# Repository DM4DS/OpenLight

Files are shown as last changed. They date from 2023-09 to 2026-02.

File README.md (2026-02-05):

# OpenLight
OpenLight is an OpenSource alternative to the copyrighted UniLight.
So feel free to mod / share / whatever you like.

#update 05.02.2026

Uploaded a schematic - not proud of it but better than nothing.
Pay attention, if you use a different Arduino, that your PINs must maybe adapted.
I am almost sure that not all Arduinos Pin 9 is a PWM pin. Maybe it is, check that!
Also with the Output bin. If you Arduino has more then 1 Output Pin with the same number, just try the other one.
Nothing should happen if you connect it to the wrong one. Test it wih a normal LED before you flashbang a 200W LED...

Hope you enjoy the project as I do and feel free to use it for whatever you wanna control on your RC Car / Plane / Boat / submarine / UFO .....

#update 17.05.2024:

Uploaded a new INO especially for WS2812 LED strips/Plates with super easy to configure large number LED strips/plates.
You no longer have to write EACH Led per line!
NO, now tell your max number and ALL LEDs are lighting /turn off with 1 single line of code!
Also included a random pattern, with random coloring as example!
Try it, it is in the file:
OpenLight_DM4DS_v1_64er_RND_-Channel_PMW_WS2812_flash_v2.ino

#update 20.nov.2013:
Now OpenLight supports WS2812 programmable LEDs!
Thanks to AdaFruit for the library.
_________________________________________
If you have questions, please first look into the code. Most lines are commented.
If you still have questions, feal free to ask!

What to do:
- Update the parts list
- Schematics but it should be fine while it is commented in the INO file already (scroll down there is one and I am not proud)
- Update the 3D files for different usecases
- look over everything and update (partly done especially for high LED number WS2812 strips/plates)
- no idea
- something

Done:
- implement WS2812 programmable LED code. What a fun to play with them...
- optimized for WS2812 high number strips or plates! USE the RND v2 version and you will see it in the code

One of my non-ws2812 actuall setups:
- Arduino Micro 5V ( https://amzn.to/3rs5dHM )
- StepUp for my 33V LEDs from 3-6S usage ( https://amzn.to/3PStbVL - 250W ) (https://amzn.to/3Rz43oo -30W )
- MosFET Board ( https://amzn.to/3PUwV9A ) - to handle the watts and switch straight from the arduino output!
- XT60 input for the 3-6S power ( https://amzn.to/3ZEPVfl )
- XT30 ( https://amzn.to/465O8m1 ) output to the LED (30W - 33V 18x26mm ion my case but have not found a EU-Link :( )
- 30W are bright!

The LEDs are getting fast/really hot, if you turn them on for too long. For a "blink" they don´t need to stay on for 250ms!
Mine are only 10ms on, that is enough to light them up and immideatly cool the down during wait for the next 10ms blink!
So I don´t need extra heatsinks under the 30W LEDs!

WS2812 setup:
- Arduino Micro 5V ( https://amzn.to/3rs5dHM )
- WS2812D IP67 LEDs ( https://amzn.to/3GaOLPT )
- to provide the "power" for the LEDs I use a stepDown to 5V - so my RX is not perma under load. ( https://amzn.to/3syo58B )
- as power connectors as always XT30/60
- the WS2812 had it´s own connector, maybe you need one for yours, so keep an eye on that

Have fun testing/modifying. Maybe you are able to post a video and link it to me or in the RC-Network Thread:
https://www.rc-network.de/threads/openlight-unilight-in-eigenbau.11972603/

All the best - stay safe - stay healthy
DM4DS - Sandor

______________________________________________________
I do have a cold, voice is coming back slowly and my Samsung S8+ is not "fast enough" to capture the 10ms blink of the LED with its immens brightnes...
Try do make a better video, mabye as project video on youtube, so follow on @youtube, you don´t miss it.

https://github.com/DM4DS/OpenLight/assets/36482423/3efae417-0a31-46c0-ac7d-e3dbd7b221c7

https://github.com/DM4DS/OpenLight/assets/36482423/7b8483a2-6c0d-4a4b-bf42-8d83a4e4f952

https://github.com/DM4DS/OpenLight/assets/36482423/4f2229dc-e15b-4664-8377-f4358281effc

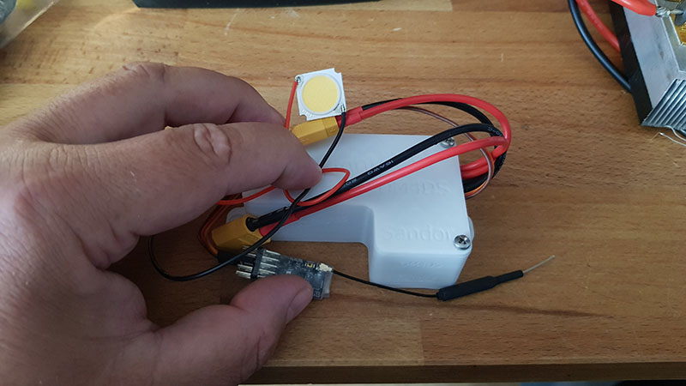
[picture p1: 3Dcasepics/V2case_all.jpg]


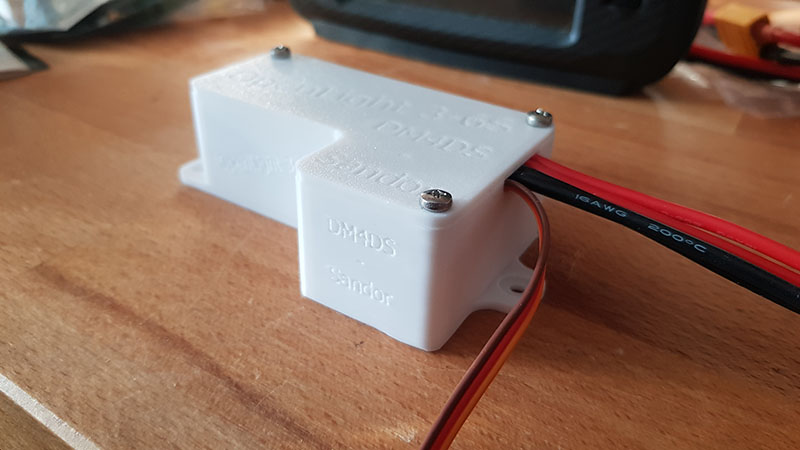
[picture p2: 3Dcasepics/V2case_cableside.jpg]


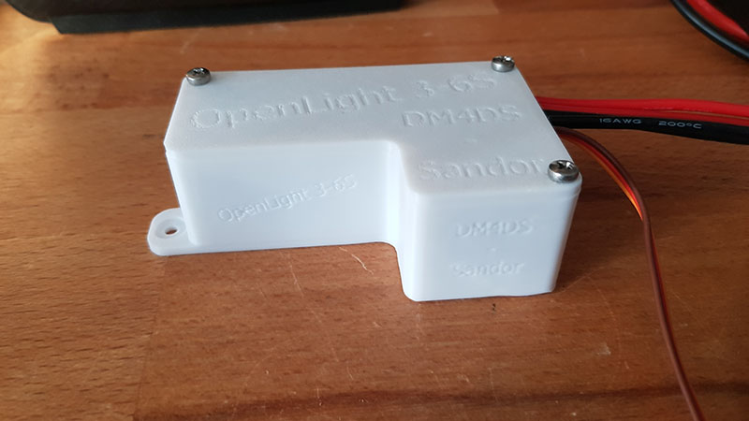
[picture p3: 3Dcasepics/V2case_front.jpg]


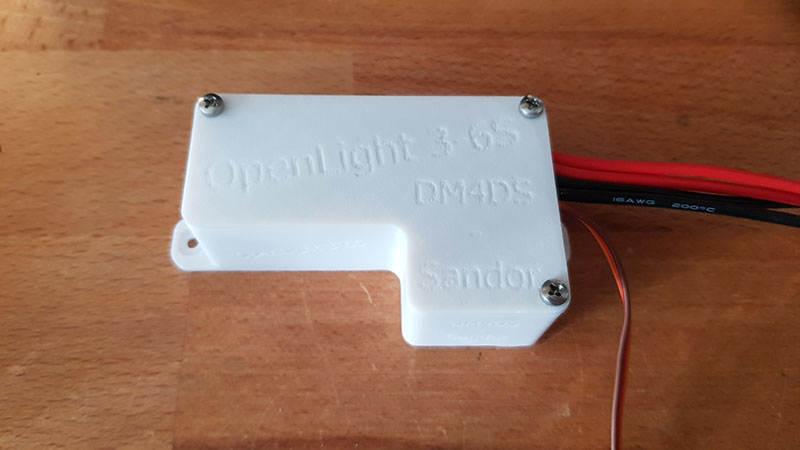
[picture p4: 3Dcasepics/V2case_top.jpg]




Please forgive me, but I am no Artist who loves to make Schematics:
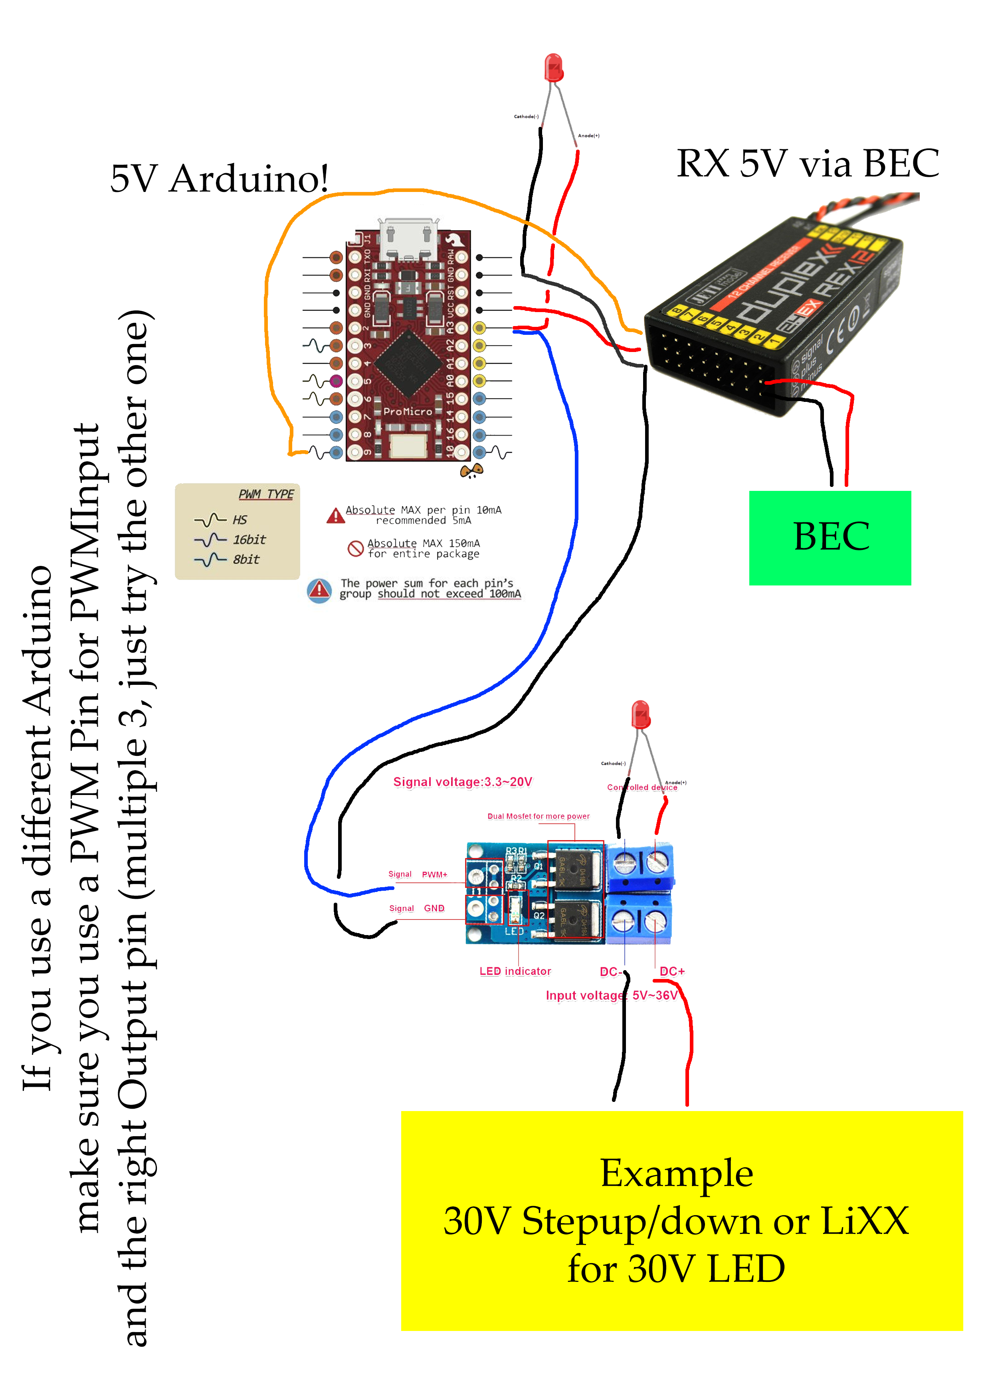
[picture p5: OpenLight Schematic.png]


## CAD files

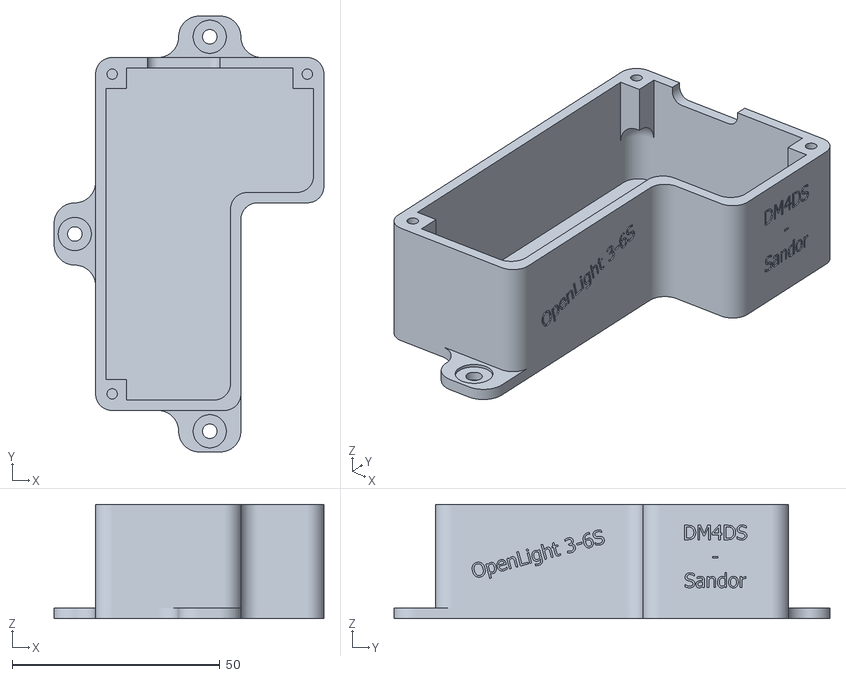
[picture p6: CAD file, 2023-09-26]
OpenLight_Micro_bottom_DM4DS_v2.stl
65.0 x 105.0 x 27.5

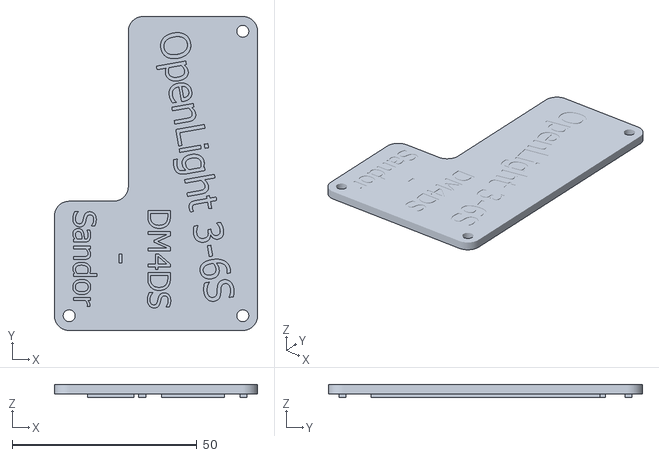
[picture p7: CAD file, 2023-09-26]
OpenLight_Micro_top_DM4DS_v2.stl
55.0 x 85.0 x 3.50

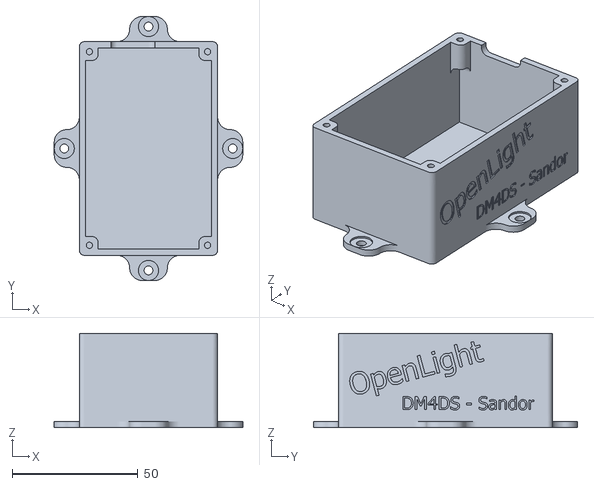
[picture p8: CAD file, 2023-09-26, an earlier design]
OpenLight_Micro_bottom_DM4DS_v1.stl
75.0 x 105.0 x 37.5

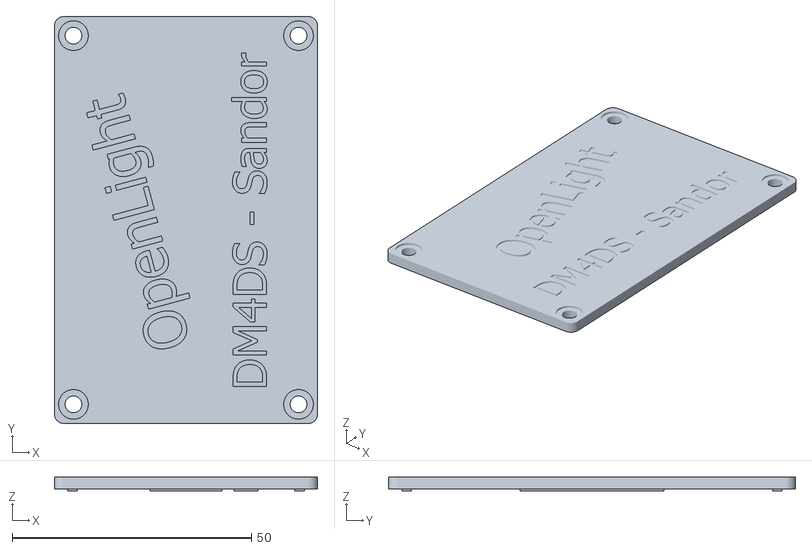
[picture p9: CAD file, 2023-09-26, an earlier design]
OpenLight_Micro_top_DM4DS_v1.stl
55.0 x 85.0 x 2.90

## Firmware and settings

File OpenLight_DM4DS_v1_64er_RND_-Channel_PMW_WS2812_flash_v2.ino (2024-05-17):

// OpenLight (GPL v3) + no commercial use without permission! Free to modify but you have to name me in your project.
// share alike / this is also for the 3D Printed parts, not only the arduino code. Thanks and enjoy it!
//
// I am sure this will be updated from time to time, so come back for the updates.

// The/a free programmable UniLight (Copyright by https://www.unilight.at/) and modifyable for your needs! Open Source. 
// to realise Light schemes to your vehicle - plane - truck - crawler - boot - etc.
// it is based on Arduino (https://www.arduino.cc/) - in my case I use a Arduino Micro 5V
// to power it straight from the 5V Servo port of my Receiver. Just plug it in and the arduino
// is doing its job.
//
//
// How does it work:
// On the "PWMInput1" Pin (in my case D9) the PWM from the receiver is read
// with a following IF the position of your source / switch is detected and translated in
// a specific blink scheme / perma light if you want (but look for the heat if you are using high power LED).
//
// In the example:
// full low < 1200 uS = no light at all
// mid range >1200 <1600 = slow blinking
// high range >1600 = fast blinking
// /feel free to express yourself in building your own blink schemes by adjusting the timings.
//
// while the LED´s generating a lot of heat if the are turned on for long time, I only switch them on
// for 10 mS! That is enough to get the needed flash and stay cool, but feel free to modify it for your needs!
// In the example only LED1 Pin 3 is connected as output to a MosFET Board, but I already defined 4 / 5 also if you need them
// copy & paste the code and change the LED1 to LED2 / LED3.
// 
// As I said, I use a 5V Arduino Micro, so I can connect it straight to a free RX channel for the PWM Signal + 5V to power
// the Arduino. Win win :)
// no special lybraries are needed, so it should be fine to use "almost" any Arduino you have laying around. Try it.
// 
// watch in the serial monitor/plotter your RX input. If there is nothing detected, it can´t work.
// I had the case that with a cheap SERVO TESTER it was not working, but with a actuall RX it is always 100% working!
// So I looked with the oscilloscope on the PWM of the Servo tester and omg, that was distorted and no wonder it was not working.
// Keep that in mind, if you maybe test on the bench.
//
// UPDATE FOR WS2812 LEDs.
// Support for WS2812 LEDs implemented , with the need of 1 library. The Library you need to install is named: AdaFruit NeoPixel
// Without the library, you will receive an error message :)
// Have fun, playing with the "onewire" LEDs.
// As you see in the code, it is implemented in the "mid" position. Feel free to midify.
// now - let´s blink :)
//
// DM4DS - Sandor
//
// Link for the rc-network thread: https://www.rc-network.de/threads/openlight-unilight-in-eigenbau.11972603/
// Here´s the code:


//WS2812 Part:
#include <Adafruit_NeoPixel.h>
#ifdef __AVR__
#include <avr/power.h>
#endif
#define PIN 6 // which PIN the DIN from the WS2812 is connected
#define NUMPIXELS 64 // attached numbers of WS2812 LEDs (max you wanna use)
Adafruit_NeoPixel pixels = Adafruit_NeoPixel(NUMPIXELS, PIN, NEO_GRB + NEO_KHZ800);

int ws2812time1=25; // pause between each WS2812 LED
int ws2812time2=250; // pause between each WS2812 LED
int ws2812time3=500; // pause between each WS2812 LED
int ws2812time4=1000; // pause between each WS2812 LED
int ws2812time5=100; // pause between each WS2812 LED

//Parts for all applications
int LED1 = 3;       			// that´s the one output I´m using and is configured to blink as above described
// int LED2 = 4;				// alternative outputs if you wanna usw it for more unique lighting / uncomment - 
// int LED3 = 5;				// copy & paste the IF /digitalwrite line + insert LED2/3 instead of LED1
int PWMInput1 = 9;				// PWM Input from the Receiver
int NUM_LEDS = 64;         // Anzahl LEDs
int i = 0;                // zum zählen der LEDS
long randomNum;          // the variable which is supposed to hold the random number

void setup() {
  pinMode(LED1, OUTPUT);		// define LED1 Pin as output
//  pinMode(LED2, OUTPUT);		// uncomment if needed
//  pinMode(LED3, OUTPUT);		//        "
  pinMode(PWMInput1, INPUT);	// PWMINput1 defined as input from the RX - if you need more inputs, feel free to define more
  Serial.begin(115200);			// Serial Monitor / Plotter setting

 // initialize the pseudo-random number generator
  randomSeed(analogRead(0));
   
// WS2812 initialize  
  pixels.begin(); // Initialise WS2812
}

void loop() {							// here the magic happens
 
int pwm1 = pulseIn(PWMInput1, HIGH);
  Serial.println(pwm1);					// Serial Monitor / Plotter Output
  if(pwm1 < 1199)						// If the stick / switch is under 1200 (low) do "no blinking"
  {
    Serial.print(PWMInput1);

  digitalWrite(LED1, LOW);   
  delay(250);             

  digitalWrite(LED1, LOW);   
  delay(500);             

  }
  else
  {
    Serial.print(PWMInput1);
  }

  if(pwm1 > 1801)						// if the stick / switch is over 1800 (full up/on) fast blinking on PIN LED1
  {
    Serial.print(PWMInput1);

  digitalWrite(LED1, HIGH);       // PIN1/LED1 on for 15ms
  delay(15);              
  digitalWrite(LED1, LOW);   			// PIN1/LED1 low means Output off / no lights for 250ms
  delay(250);             
  
  digitalWrite(LED1, HIGH);       // PIN1/LED1 on again for 15ms
  delay(15);              
  digitalWrite(LED1, LOW);   			// PIN1/LED1 off again, this time for 750ms
  delay(750);             

 digitalWrite(LED1, HIGH);        // PIN1/LED1 on again for 25ms
  delay(25);              
  digitalWrite(LED1, LOW);         // PIN1/LED1 off again for 1250ms
  delay(1250);             

  }
  else
  {
    Serial.print(PWMInput1);
  }
  if((pwm1 < 1800)&&(pwm1 > 1200))		// if the stick / switch is in the middle (>1200<1800) blink slower
  {
    Serial.print(PWMInput1);
// this time we are "running" 10 WS2812 LEDs in green color full brightness one after another
    
{
  for (int i = 0; i < NUM_LEDS; i++ ) {                   // count 1+1 until the last LED is reached (defined in NUM_LEDS)
pixels.setPixelColor(i, pixels.Color(255,255,255));       // set all NUM_LEDS to 255,255,255   
    }
}

pixels.show();
delay (ws2812time1);

// reset all WS2812 LEDs to "0" / OFF

{
  for (int i = 0; i < NUM_LEDS; i++ ) {             // count 1+1 until the last LED is reached (defined in NUM_LEDS)
pixels.setPixelColor(i, pixels.Color(0,0,0));       // set all NUM_LEDS to 0,0,0 (OFF)
    }
}

pixels.show(); // send the "0" "command" to the WS2812 LEDs
delay (ws2812time3);

{
  for (int i = 0; i < NUM_LEDS; i++ ) {                // count 1+1 until the last LED is reached (defined in NUM_LEDS)
pixels.setPixelColor(i, pixels.Color(255,255,255));    // set all NUM_LEDS to 255,255,255
    }
}

pixels.show();
delay (ws2812time1);

// reset all WS2812 LEDs to "0" / OFF
{
  for (int i = 0; i < NUM_LEDS; i++ ) {         // count 1+1 until the last LED is reached (defined in NUM_LEDS)
pixels.setPixelColor(i, pixels.Color(0,0,0));   // set all NUM_LEDS to 0,0,0 (OFF)
    }
}

pixels.show(); // send the "0" "command" to the WS2812 LEDs
delay (ws2812time3);

{
  for (int i = 0; i < NUM_LEDS; i++ ) {                 // count 1+1 until the last LED is reached (defined in NUM_LEDS)
pixels.setPixelColor(i, pixels.Color(255,255,255));     // set all NUM_LEDS to 255,255,255
    }
}

pixels.show();
delay (ws2812time2);

// reset all WS2812 LEDs to "0" / OFF

{
  for (int i = 0; i < NUM_LEDS; i++ ) {           // count 1+1 until the last LED is reached (defined in NUM_LEDS)
pixels.setPixelColor(i, pixels.Color(0,0,0));     // set all NUM_LEDS to 0,0,0 (OFF)
    }
}

pixels.show(); // send the "0" "command" to the WS2812 LEDs
delay (ws2812time4);


{
  for (int i = 0; i < NUM_LEDS; i++ ) {           // count 1+1 until the last LED is reached (defined in NUM_LEDS)
pixels.setPixelColor(random (NUM_LEDS), pixels.Color(random (0, 255),random(0, 255),random(0, 255)));     // set all NUM_LEDS to 0,0,0 (OFF)
pixels.show();
delay (ws2812time5);
    }
}

// reset all WS2812 LEDs to "0" / OFF

{
  for (int i = 0; i < NUM_LEDS; i++ ) {         // count 1+1 until the last LED is reached (defined in NUM_LEDS)
pixels.setPixelColor(i, pixels.Color(0,0,0));   // set all NUM_LEDS to 0,0,0 (OFF)
    }
}
 
pixels.show(); // send the "0" "command" to the WS2812 LEDs
delay (ws2812time4);    // pause between the next commands


  }
  else
  {
    Serial.print(PWMInput1);
  }

}

// Feel free to modify it and share it with us.
// There will be over time different hardware stuff and
// 3D printed case linked / uploaded while I building several OpenLight for my Clubmates.
// Thanks for sharing and commenting if you need somehting and not able to do it on your own.
// List how you can support me:

// Patreon: https://www.patreon.com/dm4ds
// Paypal donation: https://www.paypal.com/paypalme/dm4ds
// BMAcoffee: https://buymeacoff.ee/dm4ds
// Bitcoin: bc1qf426e46h6kdtmws4cjnu6wa3wtzy8qvctq9j9u
// Etherium: 0x3447f956194706eCDab747314CFB92Bf55428F28

// List how / where you find me:

// Youtube: https://www.youtube.com/c/DM4DS
// Printables: https://www.printables.com/de/social/461183-dm4ds/about
// Twitter: https://twitter.com/HAM_DM4DS
// Instagram: https://www.instagram.com/dm4ds/
// Thingiverse: https://www.thingiverse.com/dm4ds/
// Thangs: https://thangs.com/DM4DS
// QRZ.com: https://www.qrz.com/lookup/DM4DS
// Twitch: https://www.twitch.tv/dm4ds
// Discord Server: https://discord.gg/xSzfBCyXCZ

// List of affiliate Shops / companies:

// Amazon Affiliate Link: https://amzn.to/31TI1FC
// CopterUni: https://kurs.copteruni.de/?ref=3a0ca5

// E-post adress:
// Email: info@dm4ds.de / dm4ds@gmx.de

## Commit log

2023-09-26 3D printed cases
    Screws for the Lid are M3x10mm
    [OpenLight_Micro_bottom_DM4DS_v1.stl, OpenLight_Micro_bottom_DM4DS_v2.stl, OpenLight_Micro_top_DM4DS_v1.stl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]
2023-11-20 OpenLight INO file with WS2812 LED Support
2023-11-20 added WS2812 LED support
2023-11-20 10 green ws2812d LEDs
2024-05-17 Update for 64er WS2812B plate inlcuding random
    Big Update to easier configure high numbers of 2812B LEDS!
    You don´t need to set each LED in a single line, you now just set the max numbers and all light up at the same time OR
    as included as random pattern in the max numbers of LEDs you defined!
    SO MUCH EASIER for high LED numbers!
2026-02-05 Update README.md - added Schematics
